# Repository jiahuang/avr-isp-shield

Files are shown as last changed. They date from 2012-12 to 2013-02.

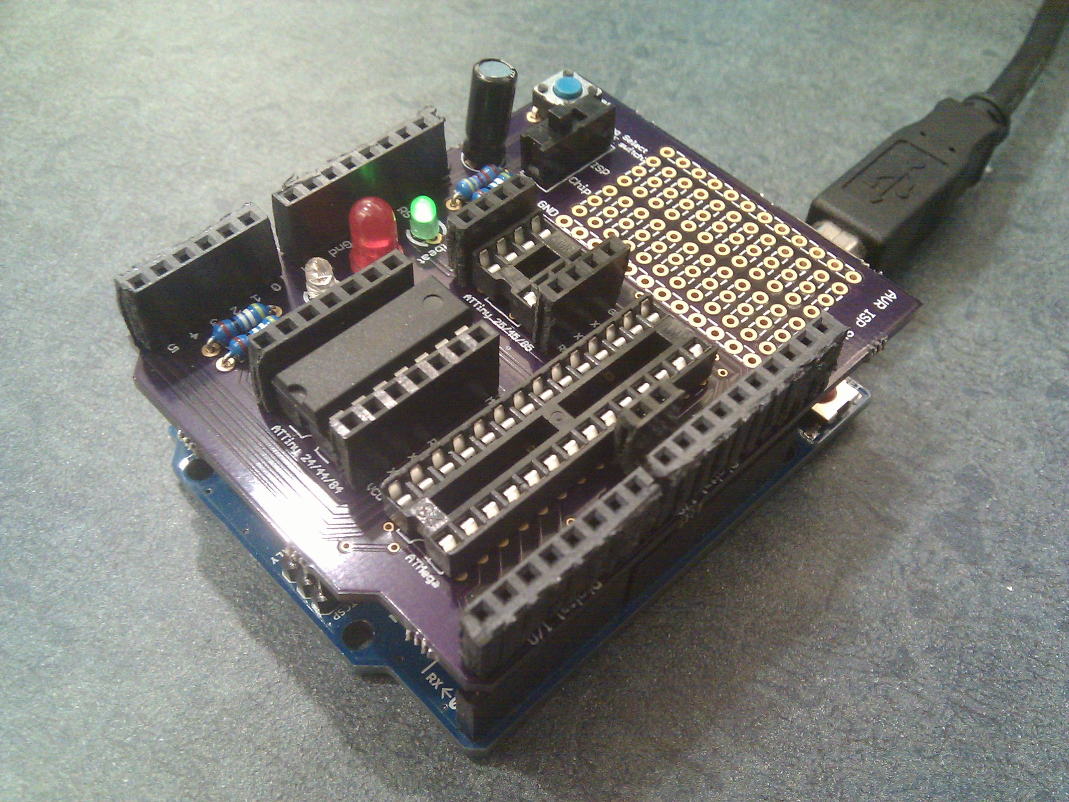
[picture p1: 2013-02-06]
images/shield_final.jpg

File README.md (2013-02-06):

#Arduino AVR Programming Shield

Use an Arduino Uno to program other AVR chips by hooking up MOSI, MISO, SCK, RST, VCC, and GND for you so your fat fingers don't mess up the programming circuit while trying to pull out the programmed chip. 

Designed for the following, but will work with chips that have the same pin setup:
* ATMega328/ATMega168 (28 pin)
* ATTiny 24/44/84 (14 pin)
* ATTiny 25/45/85 (8 pin)

Things that it does (differently?) from other AVR programming shields:
* Has a protoboard
* Breaks out all the pins for programmed chips. In case you actually programmed the chip to do something. 
* Breaks out XTAL1 & 2 pins for programming with an external crystal ocsillator
* LED indicators on heartbeat/error/programming. The LEDs even include resistors so you won't get blinded watching for error signals.
* Reset button for resetting the programmed chip without a power cycle
* Slide switch to turn on/off the 10uF connecting cap between reset and ground. Because putting in and taking out a cap is too difficult.

##The finished board
Finished board

##The board
The board

The schematic

##References
* [Sparkfun eagle libraries](https://github.com/sparkfun/SparkFun-Eagle-Libraries)
* [MIT HighLowTech](http://hlt.media.mit.edu/?p=1695)
* [Arduino AVR MegaISP](http://playground.arduino.cc/Code/MegaISP)

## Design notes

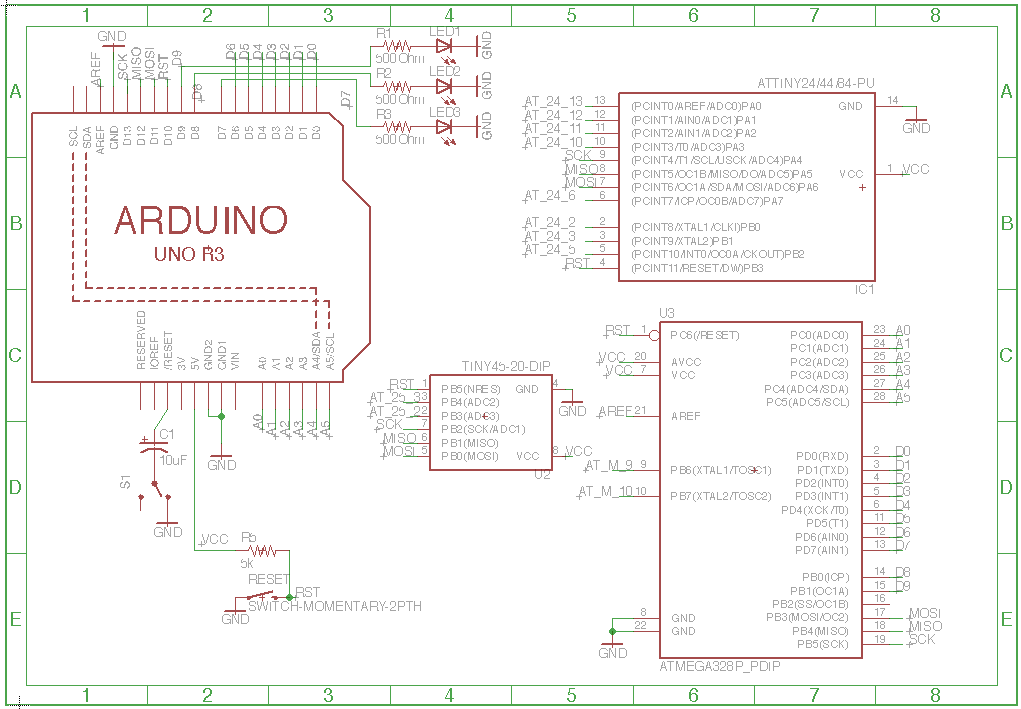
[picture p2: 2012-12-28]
images/schematic.png

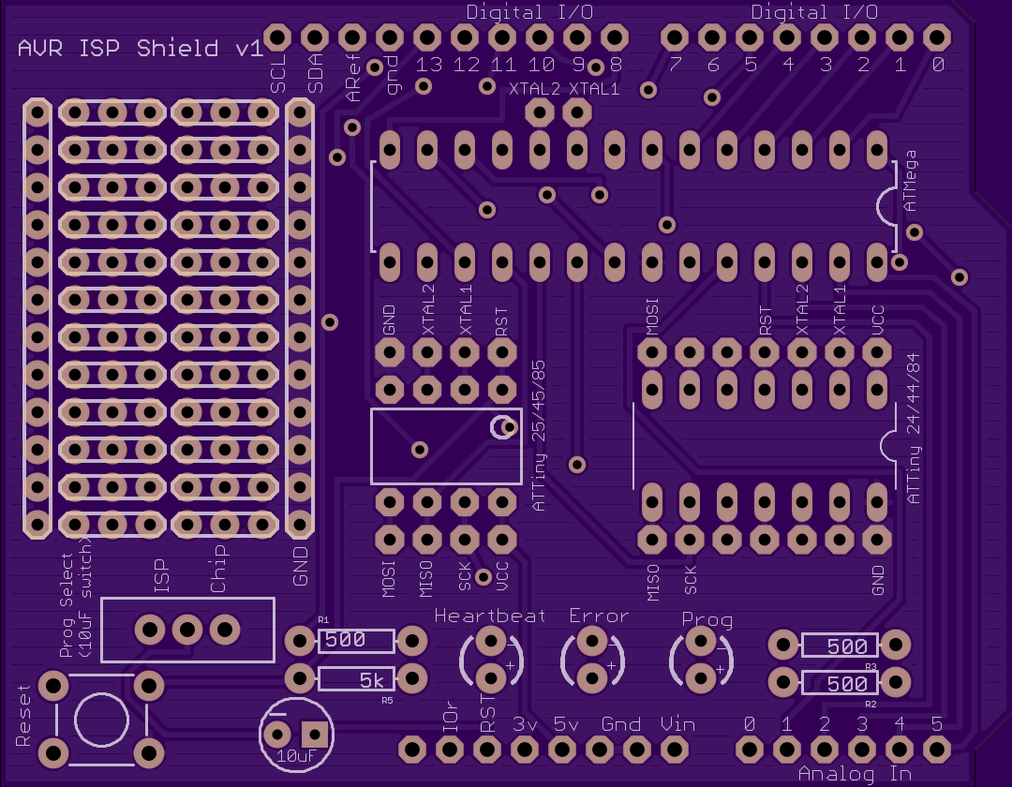
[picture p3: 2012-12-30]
images/board.png

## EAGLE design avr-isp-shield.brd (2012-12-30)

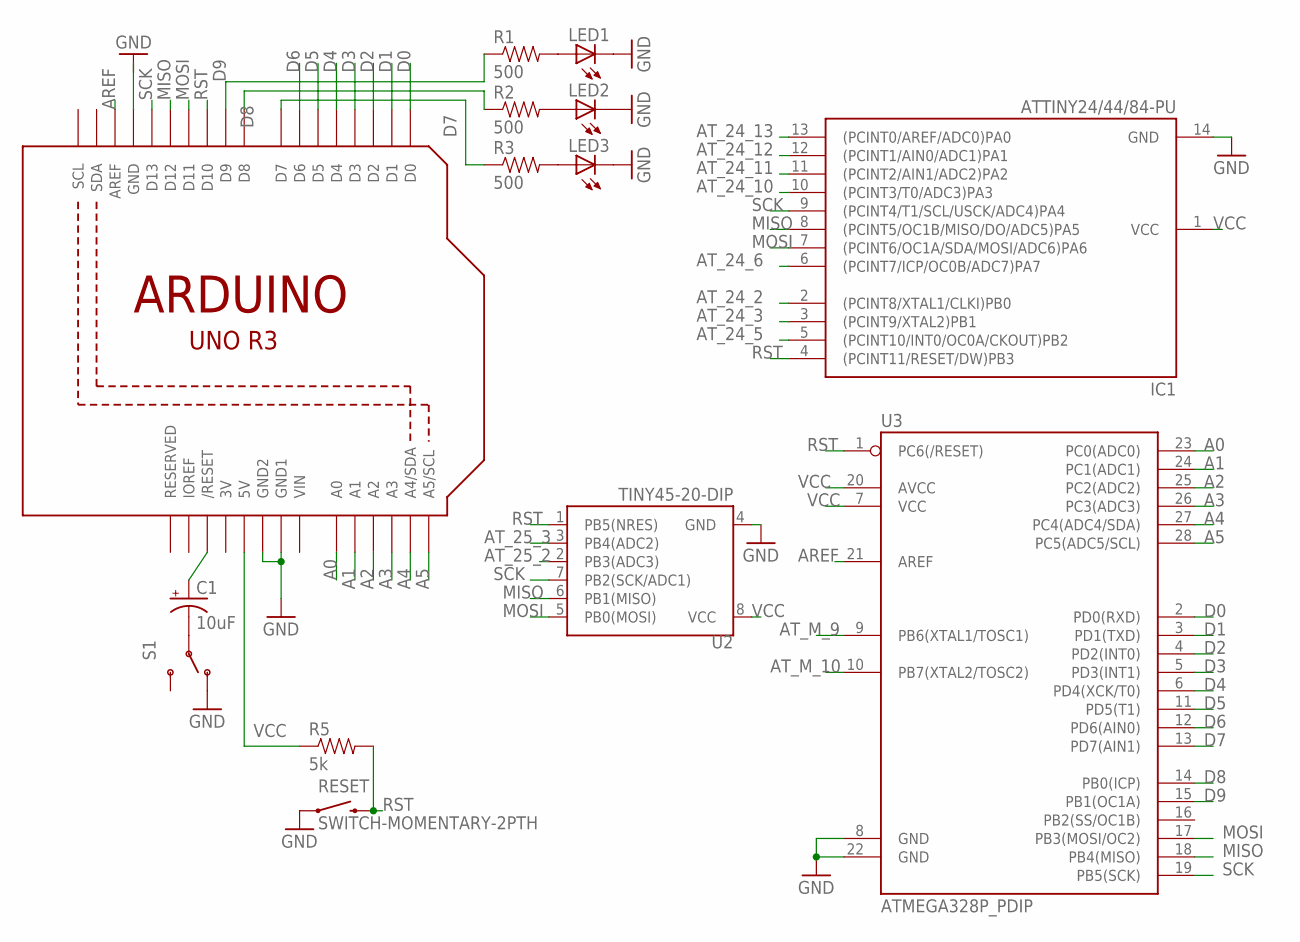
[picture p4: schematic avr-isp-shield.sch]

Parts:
C1: 10uF; CPOL-RADIAL-10UF-25V
IC1: ATTINY24/44/84-PU; DIL14
LED1, LED2, LED3: LED3MM
R1, R2, R3: 500; AXIAL-0.3
R5: 5k; AXIAL-0.3
RESET: SWITCH-MOMENTARY-2PTH; TACTILE-PTH
S1: SWITCH-SPDTPTH; SWITCH-SPDT
U2: TINY45-20-DIP; DIP08
U3: ATMEGA328P_PDIP; DIL28-3
U4: ARDUINOR3-DIMENSION; ARDUINOR3

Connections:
3V: U4.3V
A0: U3.23 (PC0(ADC0)), U4.A0
A1: U3.24 (PC1(ADC1)), U4.A1
A2: U3.25 (PC2(ADC2)), U4.A2
A3: U3.26 (PC3(ADC3)), U4.A3
A4: U3.27 (PC4(ADC4/SDA)), U4.A4 (A4/SDA)
A5: U3.28 (PC5(ADC5/SCL)), U4.A5 (A5/SCL)
AREF: U3.21 (AREF), U4.AREF
AT_24_2: IC1.2 ((PCINT8/XTAL1/CLKI)PB0)
AT_24_3: IC1.3 ((PCINT9/XTAL2)PB1)
AT_24_5: IC1.5 ((PCINT10/INT0/OC0A/CKOUT)PB2)
AT_24_6: IC1.6 ((PCINT7/ICP/OC0B/ADC7)PA7)
AT_24_10: IC1.10 ((PCINT3/T0/ADC3)PA3)
AT_24_11: IC1.11 ((PCINT2/AIN1/ADC2)PA2)
AT_24_12: IC1.12 ((PCINT1/AIN0/ADC1)PA1)
AT_24_13: IC1.13 ((PCINT0/AREF/ADC0)PA0)
AT_25_2: U2.2 (PB3(ADC3))
AT_25_3: U2.3 (PB4(ADC2))
AT_M_9: U3.9 (PB6(XTAL1/TOSC1))
AT_M_10: U3.10 (PB7(XTAL2/TOSC2))
D0: U3.2 (PD0(RXD)), U4.D0
D1: U3.3 (PD1(TXD)), U4.D1
D2: U3.4 (PD2(INT0)), U4.D2
D3: U3.5 (PD3(INT1)), U4.D3
D4: U3.6 (PD4(XCK/T0)), U4.D4
D5: U3.11 (PD5(T1)), U4.D5
D6: U3.12 (PD6(AIN0)), U4.D6
D7: R3.P$1 (1), U3.13 (PD7(AIN1)), U4.D7
D8: R2.P$1 (1), U3.14 (PB0(ICP)), U4.D8
D9: R1.P$1 (1), U3.15 (PB1(OC1A)), U4.D9
GND: IC1.14 (GND), LED1.K (C), LED2.K (C), LED3.K (C), RESET.1, S1.1 (O), U2.4 (GND), U3.8 (GND), U3.22 (GND), U4.GND1, U4.GND2
MISO: IC1.8 ((PCINT5/OC1B/MISO/DO/ADC5)PA5), U2.6 (PB1(MISO)), U3.18 (PB4(MISO)), U4.D12
MOSI: IC1.7 ((PCINT6/OC1A/SDA/MOSI/ADC6)PA6), U2.5 (PB0(MOSI)), U3.17 (PB3(MOSI/OC2)), U4.D11
unnamed: C1.1 (+), U4.RESET (/RESET)
unnamed: C1.2 (-), S1.2
unnamed: LED1.A, R1.P$2 (2)
unnamed: LED2.A, R2.P$2 (2)
unnamed: LED3.A, R3.P$2 (2)
RST: IC1.4 ((PCINT11/RESET/DW)PB3), R5.P$2 (2), RESET.3 (2), U2.1 (PB5(NRES)), U3.1 (PC6(/RESET)), U4.D10
SCK: IC1.9 ((PCINT4/T1/SCL/USCK/ADC4)PA4), U2.7 (PB2(SCK/ADC1)), U3.19 (PB5(SCK)), U4.D13
VCC: IC1.1 (VCC), R5.P$1 (1), U2.8 (VCC), U3.7 (VCC), U3.20 (AVCC), U4.5V
VIN: U4.VIN

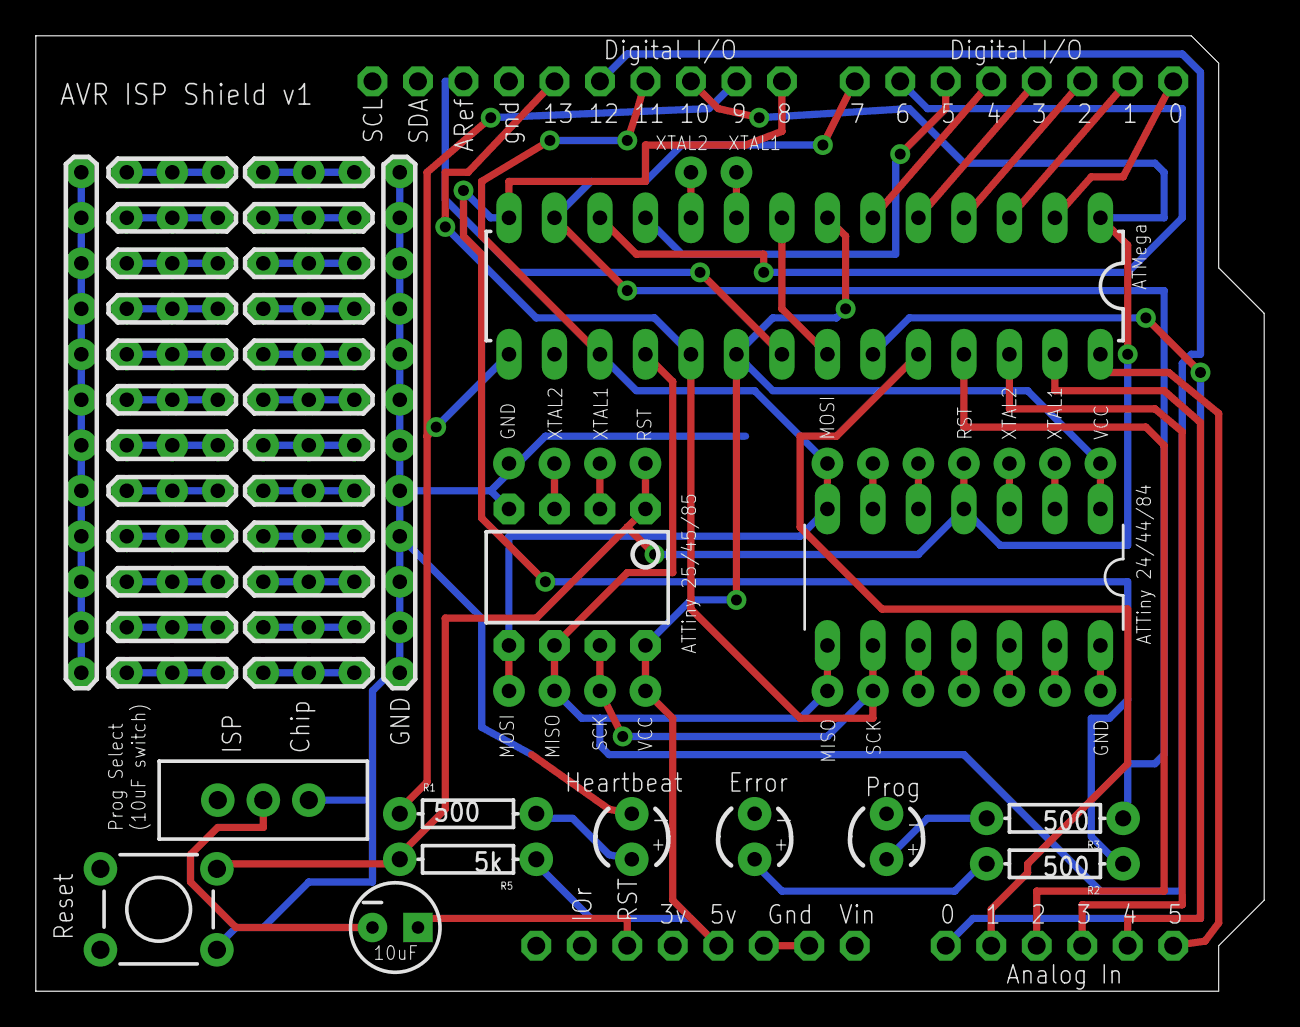
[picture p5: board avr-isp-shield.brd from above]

Board: 2 copper layers, 68.6 x 53.3 mm, 14 parts (0 on the bottom side), 28 nets.

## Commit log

2012-12-28 initial eagle project
    [avr-isp-shield.brd, avr-isp-shield.sch]
2012-12-28 images of the board
2012-12-28 adding a name
    [avr-isp-shield.brd]
2012-12-29 added ground pours
    [avr-isp-shield.brd]
2012-12-29 routing SCK correctly
    [avr-isp-shield.brd, avr-isp-shield.sch]
2012-12-30 updating board

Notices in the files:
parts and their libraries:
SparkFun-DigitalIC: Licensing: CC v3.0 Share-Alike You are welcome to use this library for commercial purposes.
